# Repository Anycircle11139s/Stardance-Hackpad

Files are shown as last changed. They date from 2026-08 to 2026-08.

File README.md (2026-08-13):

# Hack Club Stardance Hackpad

A sleek hackpad made for the Hack Club Stardance YSWS.

By: Darsh Shah ([@Anycircle11139s](https://github.com/Anycircle11139s)) or @NotALarp on slack

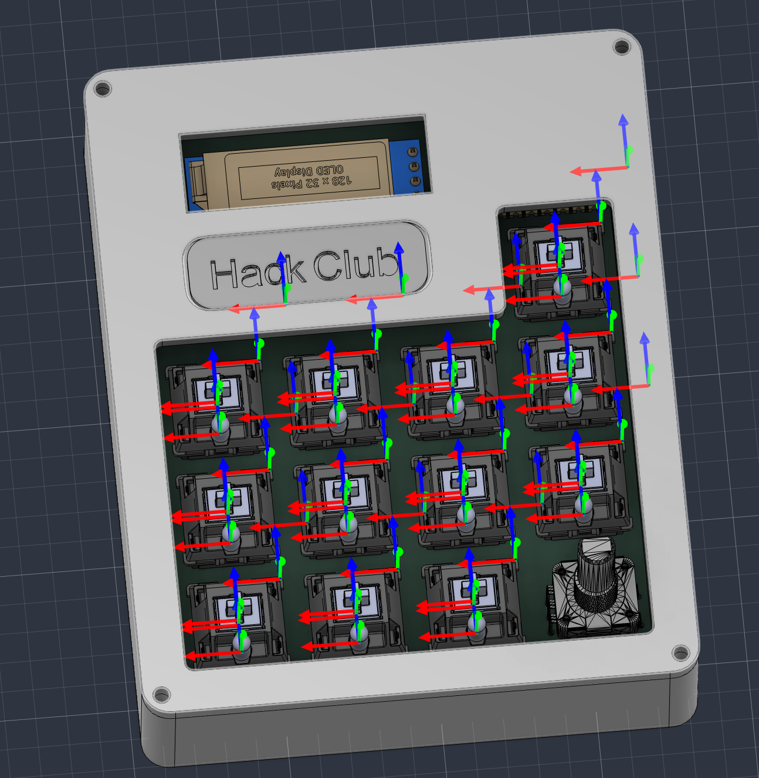
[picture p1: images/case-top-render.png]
Case render


<br>
Screenshot 2026-08-09 at 10 50 00 am
Screenshot 2026-08-09 at 10 50 07 am
Screenshot 2026-08-09 at 10 49 54 am

## Overview

I created a custom macropad with 12 keys, an OLED screen, and a rotary encoder. I built it because I wanted to get into Stardance and see how it works, and a hackpad is the perfect way to do that. I designed a custom, sleek case to fit around the PCB, and learned about different types of fillets, like tangent (G1) and curvature (G2). Building this taught me a lot about product design.

## Features

- OLED display
- 12 Cherry MX switches
- Rotary encoder
- Xiao RP2040 microcontroller
- Custom 3D printable case

## Build Steps

1. Order all the parts and 3D print the case.
2. Solder all the parts onto the PCB.
3. Place the PCB inside the case and screw on the lid.
4. Flash the firmware and enjoy!

## Firmware

- Framework: [KMK](https://github.com/KMKfw/kmk_firmware) (CircuitPython)
- Notes: Simple to flash. The OLED display shows "Hackpad", each key acts as a number key (1-12), and the rotary encoder controls volume.

Firmware files and pin mapping are in the [`firmware/`](./firmware) folder.

## Hardware

KiCad schematic, PCB layout, and Gerbers are in the [`hardware/`](./hardware) folder. 3D-printable case files are in the [`enclosure/`](./enclosure) folder. Renders and schematic/PCB screenshots are in [`images/`](./images).

## Bill of Materials

A CSV version is also available at [`BOM.csv`](./BOM.csv).

| Part | Qty | Cost Each | Notes |
|---|---|---|---|
| 0.91" OLED Display | 1 | $0.00 | From Stardance hackpad kit |
| 1N4148 diodes | 12 | $0.00 | From Stardance hackpad kit |
| Cherry MX switches | 12 | $0.00 | From Stardance hackpad kit |
| Rotary encoder | 1 | $0.00 | From Stardance hackpad kit |
| Keycaps | 12 | $0.00 | From Stardance hackpad kit |
| Xiao RP2040 microcontroller | 1 | $0.00 | From Stardance hackpad kit |
| 3D Printed Enclosure | 1 | $0.00 | Printed by Printing Legion |
| M3 Screws | 4 | $0.00 | From Stardance hackpad kit |
|PCB | 1 | $5.50 | From JLCPCB |

Total estimated cost: $5.50

## License

This project is licensed under the MIT License — see [`LICENSE`](./LICENSE) for details.

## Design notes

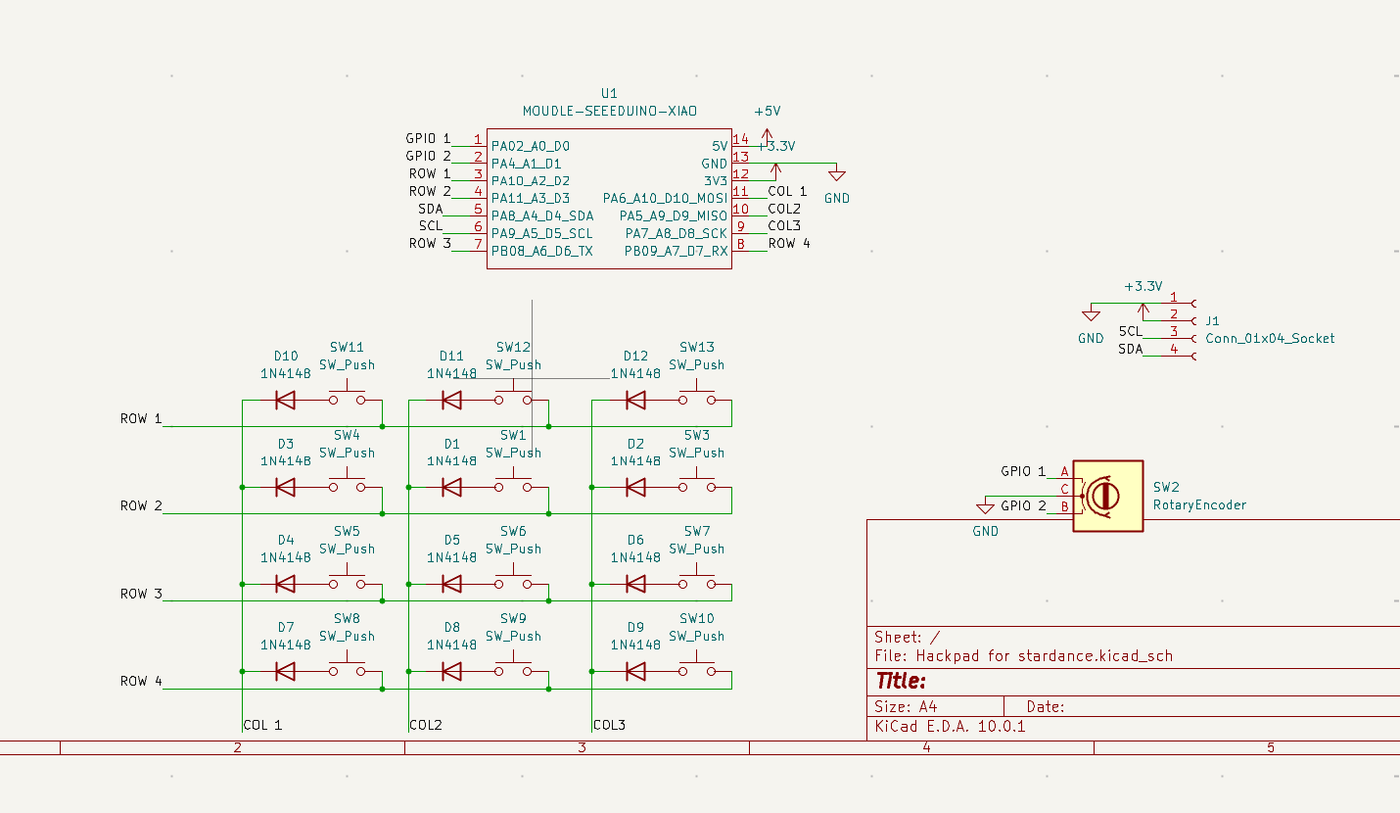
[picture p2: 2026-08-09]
images/schematic.png

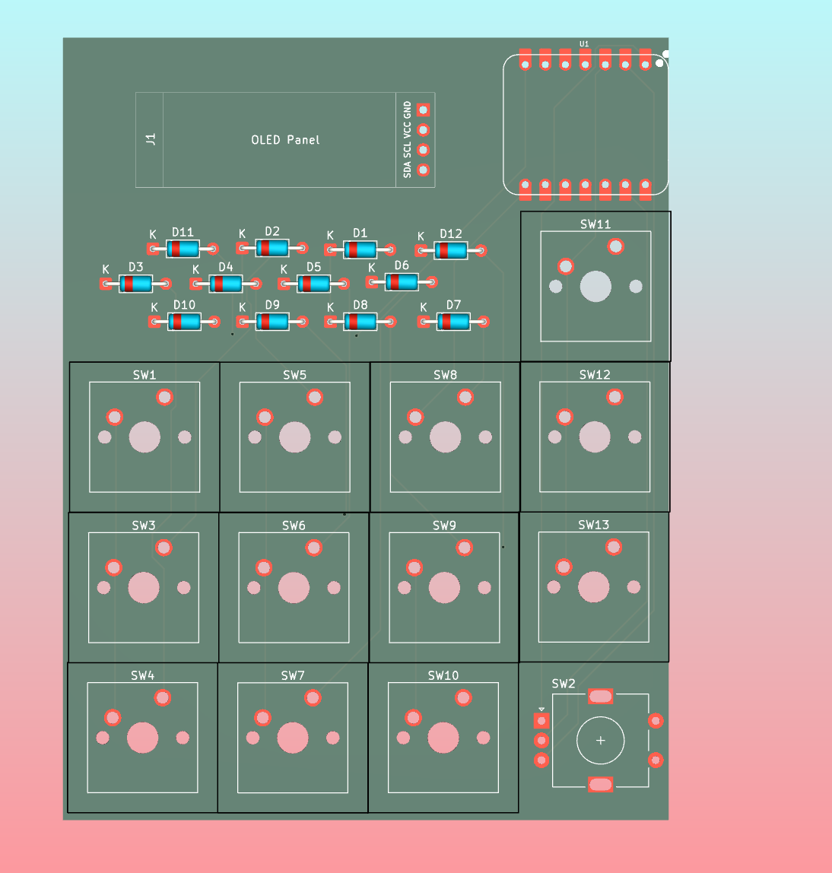
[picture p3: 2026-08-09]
images/pcb-copper-layers.png

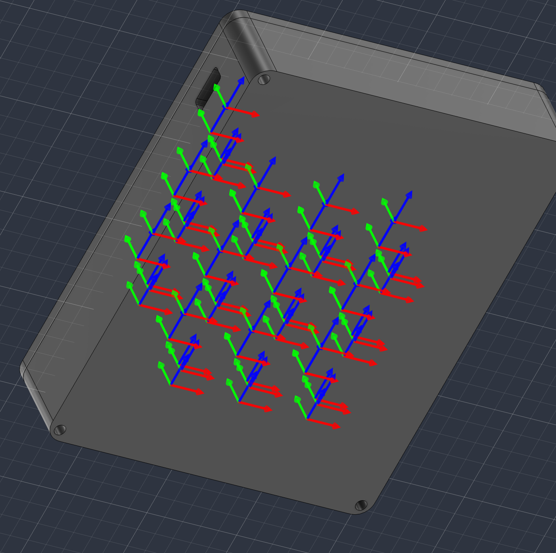
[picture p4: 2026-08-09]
images/case-bottom-render.png

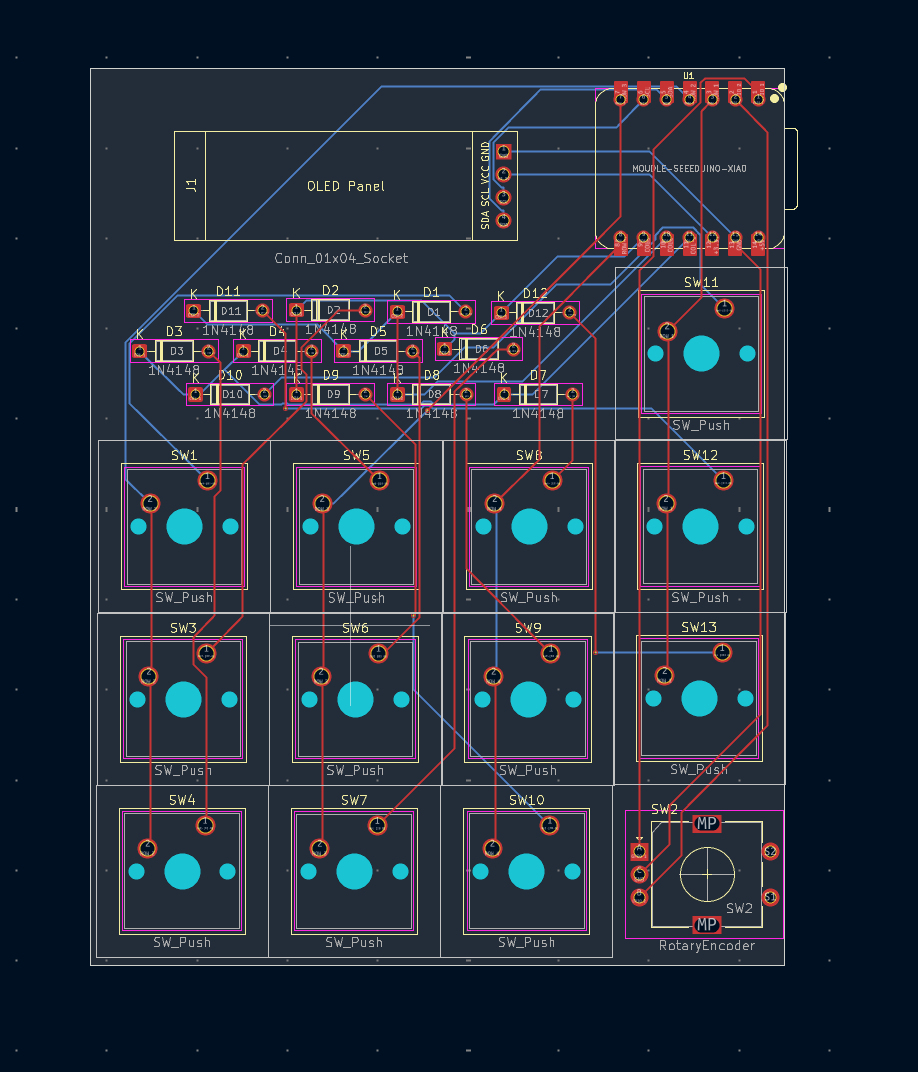
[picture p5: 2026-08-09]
images/pcb-layout.png

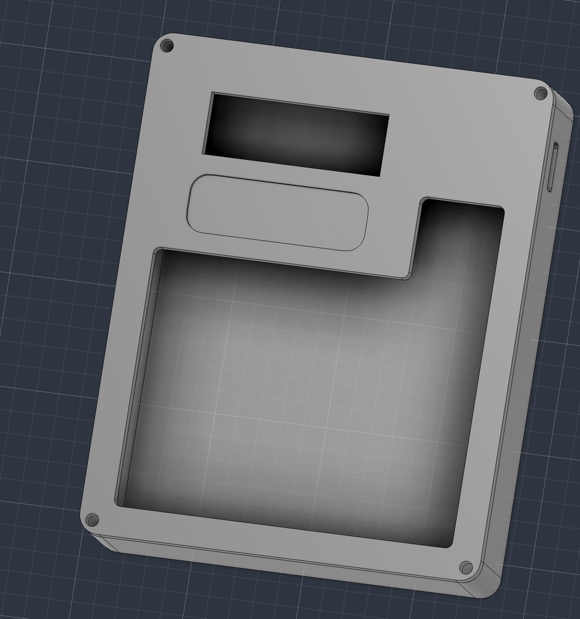
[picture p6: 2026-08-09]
images/case-top-inside.png

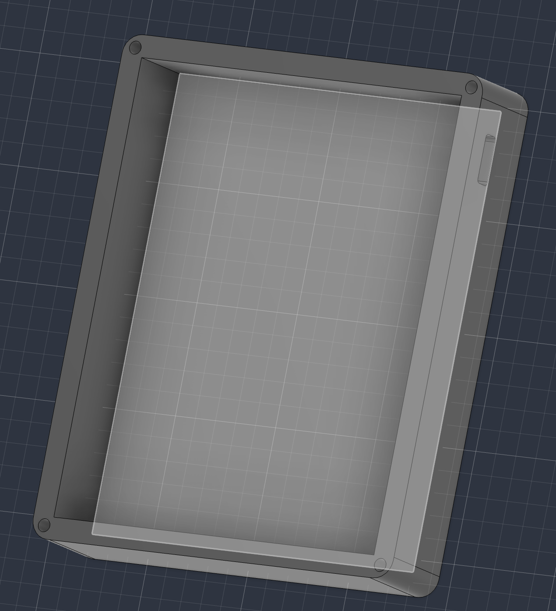
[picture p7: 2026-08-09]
images/case-bottom-inside.png

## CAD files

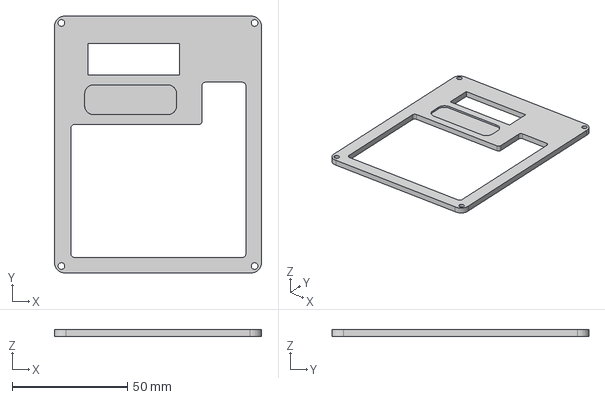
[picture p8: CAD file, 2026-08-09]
enclosure/CAD_Stardance_hackpad_case_top.step
89.9 x 111.6 x 3.00 mm

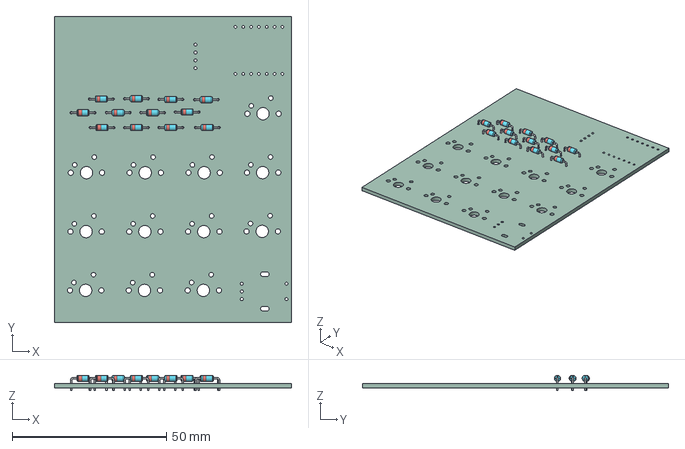
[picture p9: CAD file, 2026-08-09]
hardware/CAD_Stardance_PCB.step
76.9 x 99.3 x 5.01 mm
D_DO-35_SOD27_P7.62mm_Horizontal x 12
Hackpad for stardance_PCB

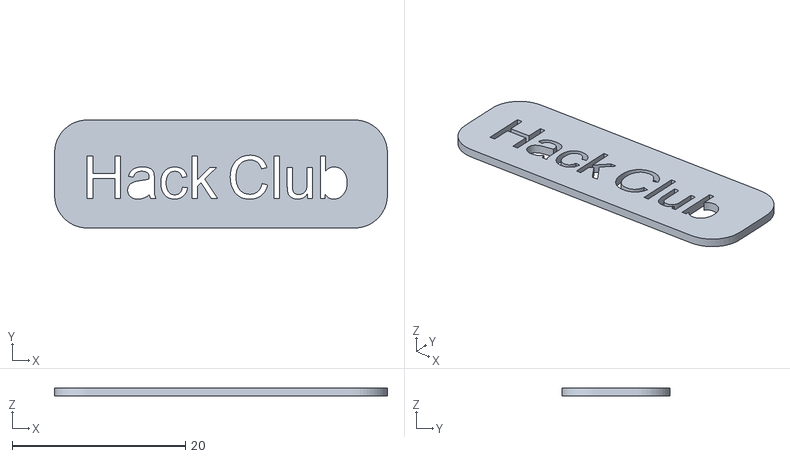
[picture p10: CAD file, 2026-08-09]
Production/CAD_Stardance_hackpad_top_plate.stl
38.4 x 12.5 x 0.96

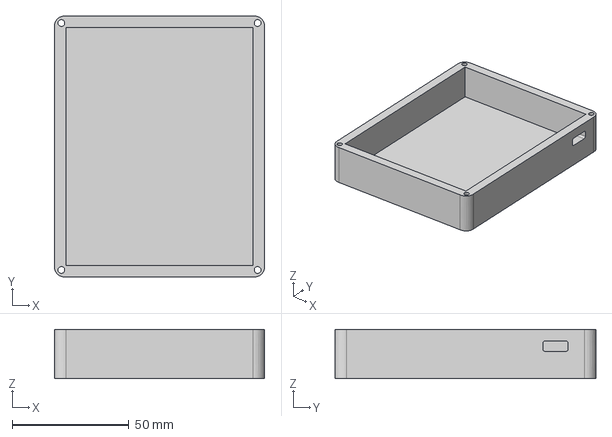
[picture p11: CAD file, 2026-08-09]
enclosure/CAD_Stardance_hackpad_case_bottom.step
89.9 x 111.6 x 21.0 mm

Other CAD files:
Production/CAD_Stardance_hackpad_case_bottom.stl
enclosure/CAD_Stardance_hackpad_top_plate.step
Production/CAD_Stardance_hackpad_case_top.stl

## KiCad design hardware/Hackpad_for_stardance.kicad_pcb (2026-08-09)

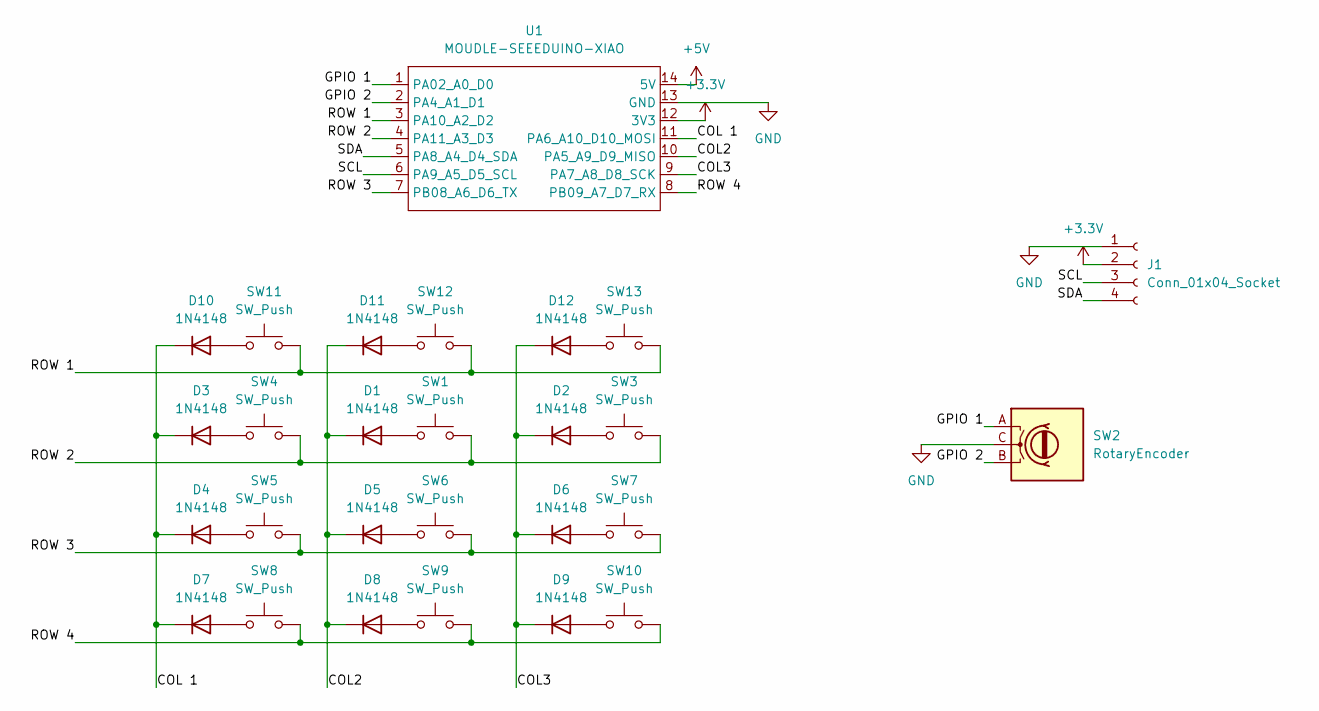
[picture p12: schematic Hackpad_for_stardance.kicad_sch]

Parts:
D1, D2, D3, D4, D5, D6, D7, D8, D9, D10, D11, D12: 1N4148; D_DO-35_SOD27_P7.62mm_Horizontal
J1: Conn_01x04_Socket; SSD1306-0.91-OLED-4pin-128x32
SW1, SW3, SW4, SW5, SW6, SW7, SW8, SW9, SW10, SW11, SW12, SW13: SW_Push; SW_Cherry_MX_1.00u_PCB
SW2: RotaryEncoder; RotaryEncoder_Alps_EC11E-Switch_Vertical_H20mm
U1: MOUDLE-SEEEDUINO-XIAO; XIAO RP2040 DIP

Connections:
+3.3V: J1.2, U1.12 (3V3)
+5V: U1.14 (5V)
/COL2: D1.1 (K), D5.1 (K), D8.1 (K), D11.1 (K), U1.10 (PA5_A9_D9_MISO)
/COL3: D2.1 (K), D6.1 (K), D9.1 (K), D12.1 (K), U1.9 (PA7_A8_D8_SCK)
/COL 1: D3.1 (K), D4.1 (K), D7.1 (K), D10.1 (K), U1.11 (PA6_A10_D10_MOSI)
/GPIO 1: SW2.A, U1.1 (PA02_A0_D0)
/GPIO 2: SW2.B, U1.2 (PA4_A1_D1)
/ROW 1: SW11.2, SW12.2, SW13.2, U1.3 (PA10_A2_D2)
/ROW 2: SW1.2, SW3.2, SW4.2, U1.4 (PA11_A3_D3)
/ROW 3: SW5.2, SW6.2, SW7.2, U1.7 (PB08_A6_D6_TX)
/ROW 4: SW8.2, SW9.2, SW10.2, U1.8 (PB09_A7_D7_RX)
/SCL: J1.3, U1.6 (PA9_A5_D5_SCL)
/SDA: J1.4, U1.5 (PA8_A4_D4_SDA)
GND: J1.1, SW2.C, U1.13 (GND)
unnamed: D1.2 (A), SW1.1
unnamed: D2.2 (A), SW3.1
unnamed: D3.2 (A), SW4.1
unnamed: D4.2 (A), SW5.1
unnamed: D5.2 (A), SW6.1
unnamed: D6.2 (A), SW7.1
unnamed: D7.2 (A), SW8.1
unnamed: D8.2 (A), SW9.1
unnamed: D9.2 (A), SW10.1
unnamed: D10.2 (A), SW11.1
unnamed: D11.2 (A), SW12.1
unnamed: D12.2 (A), SW13.1

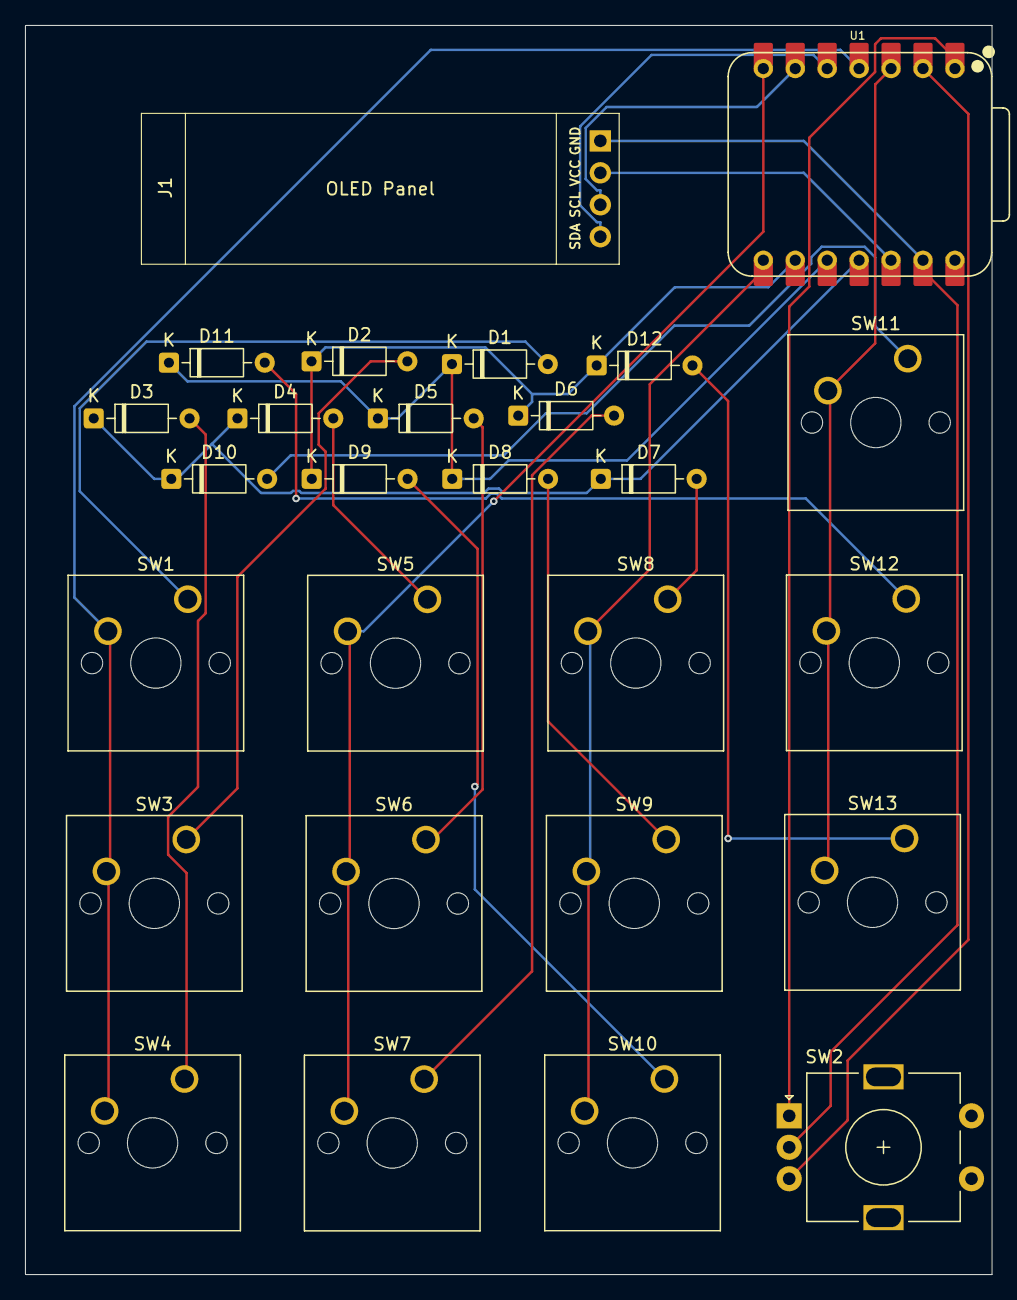
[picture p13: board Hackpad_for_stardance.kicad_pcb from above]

Board: 2 copper layers, 76.9 x 99.3 mm, 27 parts (0 on the bottom side), 25 nets.

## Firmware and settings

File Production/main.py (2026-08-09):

import board

from kmk.kmk_keyboard import KMKKeyboard
from kmk.keys import KC
from kmk.scanners import DiodeOrientation
from kmk.modules.encoder import EncoderHandler

import displayio
import terminalio
import busio
from adafruit_display_text import label
import adafruit_displayio_ssd1306

keyboard = KMKKeyboard()

keyboard.row_pins = (board.D2, board.D3, board.D6, board.D7)   
keyboard.col_pins = (board.D10, board.D9, board.D8)            
keyboard.diode_orientation = DiodeOrientation.COL2ROW


keyboard.keymap = [
    [
        KC.N1, KC.N2, KC.N3,
        KC.N4, KC.N5, KC.N6,
        KC.N7, KC.N8, KC.N9,
        KC.N10, KC.N11, KC.N12,
    ]
]

encoder_handler = EncoderHandler()
encoder_handler.pins = ((board.D0, board.D1, None, False),)  
encoder_handler.map = [((KC.VOLU, KC.VOLD),)]
keyboard.modules.append(encoder_handler)

displayio.release_displays()
i2c = busio.I2C(board.SCL, board.SDA)
display_bus = displayio.I2CDisplay(i2c, device_address=0x3C)
display = adafruit_displayio_ssd1306.SSD1306(display_bus, width=128, height=32)

splash = displayio.Group()
display.root_group = splash
text_area = label.Label(terminalio.FONT, text="Hackpad", x=35, y=15)
splash.append(text_area)

if __name__ == '__main__':
    keyboard.go()

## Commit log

2026-08-09 Add trailing commas to BOM.csv entries
    Updated BOM.csv to include trailing commas for each entry.
    [BOM.csv]
2026-08-09 Add enclosure CAD files
    [CAD_Stardance_hackpad_case_bottom.step, CAD_Stardance_hackpad_case_bottom.stl, CAD_Stardance_hackpad_case_top.step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]
